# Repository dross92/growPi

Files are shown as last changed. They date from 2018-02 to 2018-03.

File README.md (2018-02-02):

# **growPi**

#### Envirologger / Fan Controller for Raspberry Pi ####
This is a 'HAT' for Raspberry Pi 3 B.  The objective of this circuit board is to control and optimize an environment for growing plants.  Integrated Fan controller regulates temperature.

### Connections ###
* Headers for up to five i2c connections (Vcc = 5V)
* Three 4-wire 12v PWM fans
* Three relays (Lights, Fan, Water Pump)
* 12v plug powers entire board & Pi
* Push Button for manual pump control

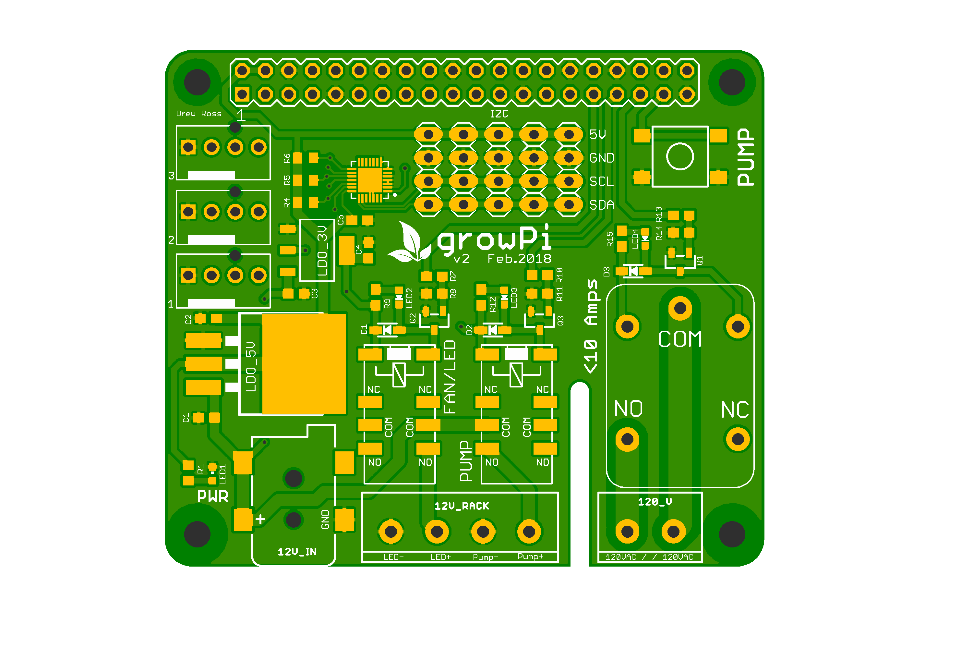
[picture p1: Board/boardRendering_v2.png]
Board


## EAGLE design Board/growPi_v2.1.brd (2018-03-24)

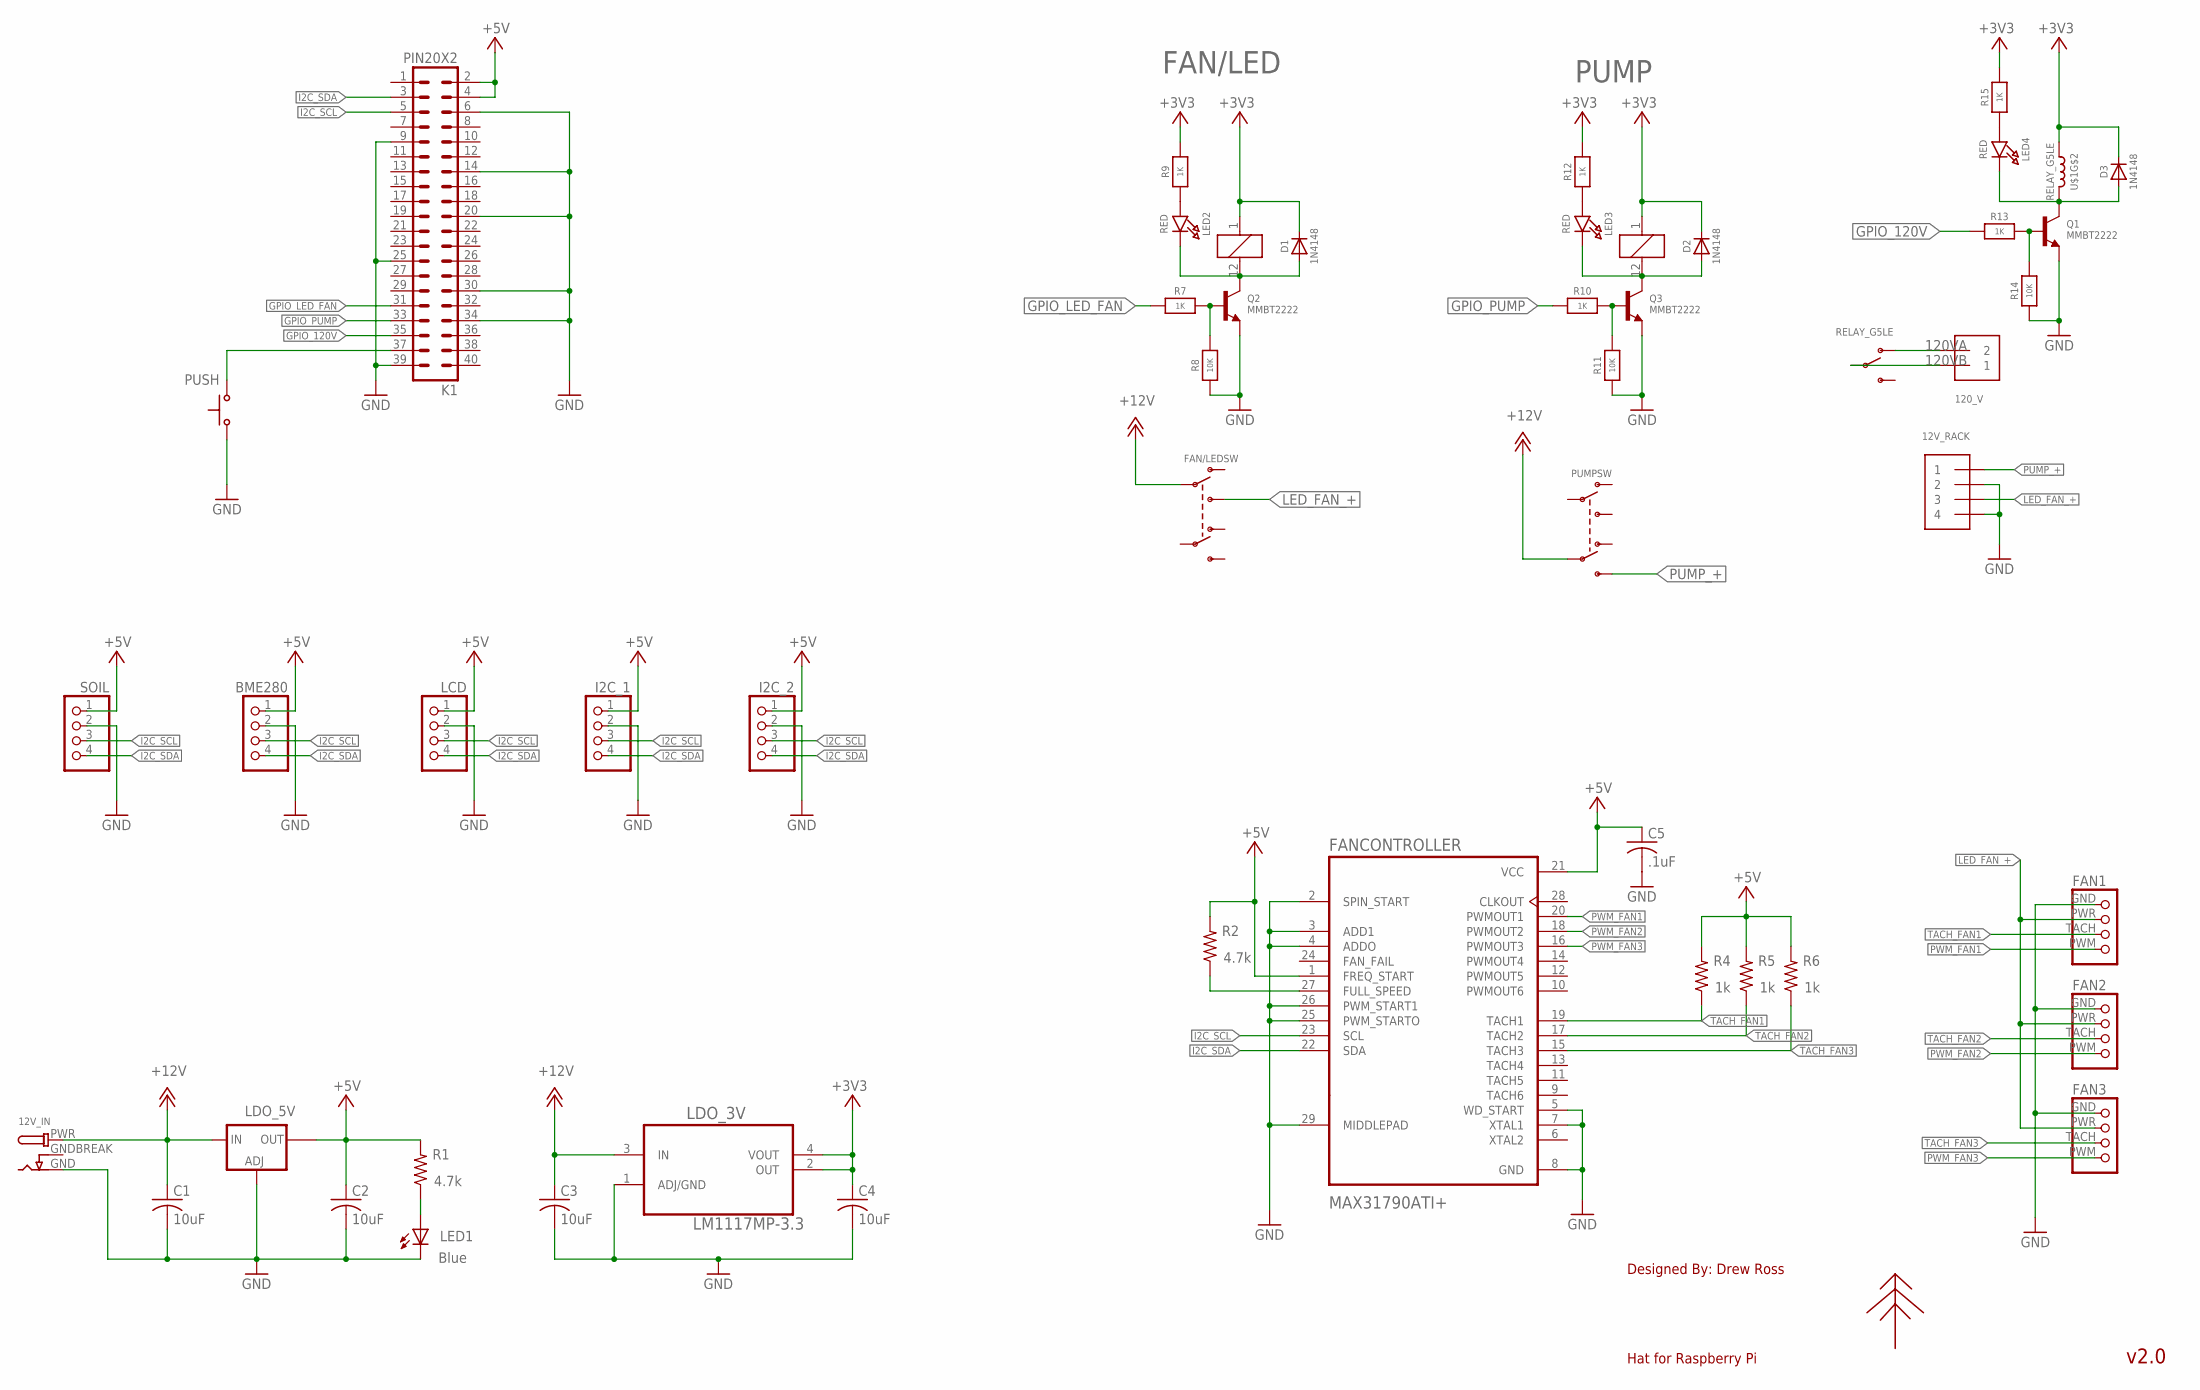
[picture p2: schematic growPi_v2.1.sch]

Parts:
12V_IN: DCBARRELSMT_CORRECT; DCJACK_2MM_SMT
12V_RACK: TERMBLOCK_1X4-5.0MM
120_V: TERMBLOCK_1X2-5.0MM
BME280: PINHD-1X4; 1X04
C1, C2, C3, C4: 10uF; C0603
C5: .1uF; C0603
D1, D2, D3: 1N4148; SOD-323
FAN1, FAN2, FAN3: 4PIN-MOLEX-FAN; 4PIN-FAN-HEADER
FAN/LED: RELAY_NONLATCHING-EE2NUH; RELAY_EE2_NOLATCH
FANCONTROLLER: MAX31790ATI+; QFN40P400X400X80-29N
I2C_1, I2C_2: PINHD-1X4; 1X04
K1: PIN20X2; PIN_20X2
LCD: PINHD-1X4; 1X04
LDO_3V: LM1117MP-3.3; SOT230P696X180-4N
LDO_5V: LM1084IS; TO263
LED1: Blue; CHIPLED_0603
LED2, LED3, LED4: RED; CHIPLED_0603_NOOUTLINE
PLANTLOGO: PLANTLOGO; PLANT
PUMP: RELAY_NONLATCHING-EE2NUH; RELAY_EE2_NOLATCH
PUSH: PTS645SSMTR; PTS645-SMD
Q1, Q2, Q3: MMBT2222; SOT23-R
R1, R2: 4.7k; R0603
R4, R5, R6: 1k; R0603
R7, R9, R10, R12, R13, R15: 1K; 0603-NO
R8, R11, R14: 10K; 0603-NO
SOIL: PINHD-1X4; 1X04
U$1: RELAY_G5LE; RELAY_G5LE-1

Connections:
120VA: 120_V.2, U$1.3 (O)
120VB: 120_V.1, U$1.1
+3V3: C4.1, D1.C, D2.C, D3.C, FAN/LED.1, LDO_3V.2 (OUT), LDO_3V.4 (VOUT), PUMP.1, R9.2, R12.2, R15.2, U$1.2 (1)
+5V: BME280.1, C2.1, C5.1, FANCONTROLLER.1 (FREQ_START), FANCONTROLLER.21 (VCC), I2C_1.1, I2C_2.1, K1.2, K1.4, LCD.1, LDO_5V.2 (OUT), R1.2, R2.2, R4.2, R5.2, R6.2, SOIL.1
+12V: 12V_IN.PWR, C1.1, C3.1, FAN/LED.9 (P1), LDO_3V.3 (IN), LDO_5V.3 (IN), PUMP.4 (P2)
GND: 12V_IN.GND, 12V_RACK.2, 12V_RACK.4, BME280.2, C1.2, C2.2, C3.2, C4.2, C5.2, FAN1.GND (1), FAN2.GND (1), FAN3.GND (1), FANCONTROLLER.2 (SPIN_START), FANCONTROLLER.3 (ADD1), FANCONTROLLER.4 (ADDO), FANCONTROLLER.5 (WD_START), FANCONTROLLER.7 (XTAL1), FANCONTROLLER.8 (GND), FANCONTROLLER.25 (PWM_STARTO), FANCONTROLLER.26 (PWM_START1), FANCONTROLLER.29 (MIDDLEPAD), I2C_1.2, I2C_2.2, K1.6, K1.9, K1.14, K1.20, K1.25, K1.30, K1.34, K1.39, LCD.2, LDO_3V.1 (ADJ/GND), LDO_5V.1 (ADJ), LED1.C, PUSH.1, PUSH.2, Q1.2 (E), Q2.2 (E), Q3.2 (E), R8.1, R11.1, R14.1, SOIL.2
GNDBREAK: 12V_IN.GNDBREAK
GPIO_120V: K1.35, R13.1
GPIO_LED_FAN: K1.31, R7.1
GPIO_PUMP: K1.33, R10.1
I2C_SCL: BME280.3, FANCONTROLLER.23 (SCL), I2C_1.3, I2C_2.3, K1.5, LCD.3, SOIL.3
I2C_SDA: BME280.4, FANCONTROLLER.22 (SDA), I2C_1.4, I2C_2.4, K1.3, LCD.4, SOIL.4
LED_FAN_+: 12V_RACK.3, FAN1.PWR (2), FAN2.PWR (2), FAN3.PWR (2), FAN/LED.8 (S1)
unnamed: FANCONTROLLER.27 (FULL_SPEED), R2.1
unnamed: D1.A, FAN/LED.12 (2), LED2.C, Q2.3 (C)
unnamed: Q2.1 (B), R7.2, R8.2
unnamed: LED2.A, R9.1
unnamed: D2.A, LED3.C, PUMP.12 (2), Q3.3 (C)
unnamed: Q3.1 (B), R10.2, R11.2
unnamed: D3.A, LED4.C, Q1.3 (C), U$1.5 (2)
unnamed: LED3.A, R12.1
unnamed: LED1.A, R1.1
unnamed: K1.37, PUSH.3 (S), PUSH.4 (S)
unnamed: Q1.1 (B), R13.2, R14.2
unnamed: LED4.A, R15.1
PUMP_+: 12V_RACK.1, PUMP.5 (S2)
PWM_FAN1: FAN1.PWM (4), FANCONTROLLER.20 (PWMOUT1)
PWM_FAN2: FAN2.PWM (4), FANCONTROLLER.18 (PWMOUT2)
PWM_FAN3: FAN3.PWM (4), FANCONTROLLER.16 (PWMOUT3)
TACH_FAN1: FAN1.TACH (3), FANCONTROLLER.19 (TACH1), R4.1
TACH_FAN2: FAN2.TACH (3), FANCONTROLLER.17 (TACH2), R5.1
TACH_FAN3: FAN3.TACH (3), FANCONTROLLER.15 (TACH3), R6.1

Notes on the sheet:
Designed By:
Hat for Raspberry Pi
Drew Ross
v2.0

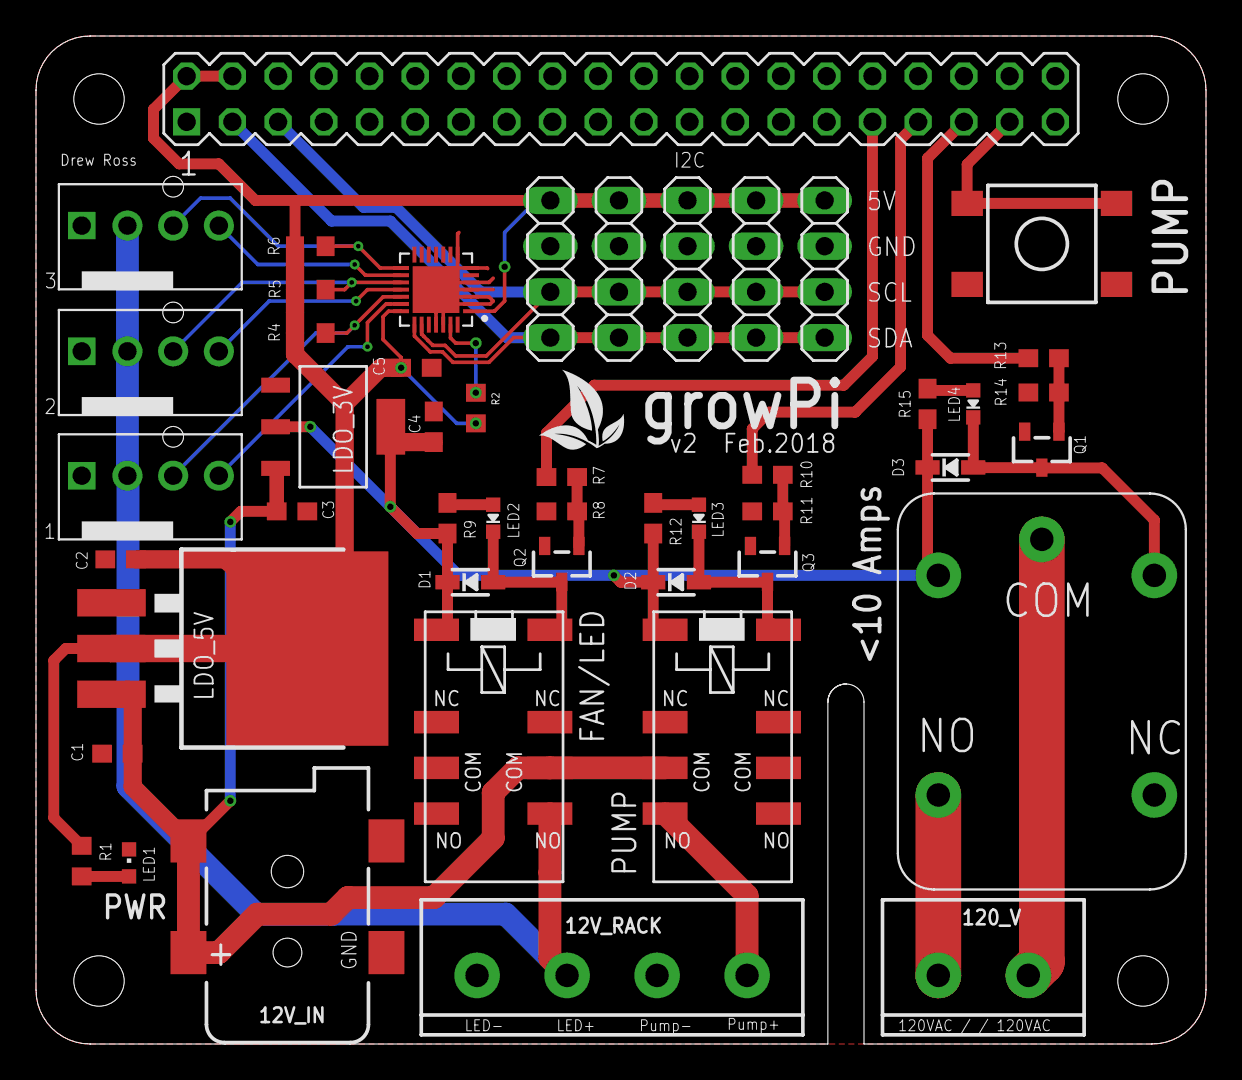
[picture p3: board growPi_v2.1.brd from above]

Board: 2 copper layers, 65.0 x 56.0 mm, 49 parts (0 on the bottom side), 31 nets.

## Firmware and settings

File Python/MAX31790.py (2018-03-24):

#!/usr/bin/python
"""
* MAX31790 6-Channel PWM-Output Fan RPM Controller Library
* 
* Author : Drew Ross
* 
* Notes:
* _ Use specifc POR settings from hardware
* - If less than 6 fans, use consecutive channels starting at 1
* - 
* - 
* - 
* 
"""

import smbus
import time

bus = smbus.SMBus(1)

#Characteristics
maxAddr = 0x20   # I2C Address (ADD0 & ADD1 = GND)
#maxAddr = 0x40 >> 1   #Datasheet defined 7bit address shifted = 0x20
pulsePerRev = 2  # Number of fan tach pulses  per fan revolution (NP)
tachPeriods = 4  # Chip Default - number of 8192Hz cycles per motor something (SR)


#------------------------Definitions----------------
#FREQS
PWMFREQ_25Hz  = 0b0000
PWMFREQ_30Hz  = 0b0001
PWMFREQ_35Hz  = 0b0010
PWMFREQ_100Hz = 0b0011
PWMFREQ_125Hz = 0b0100
PWMFREQ_5kHz  = 0b1001
PWMFREQ_25kHz = 0b1011

#Spin Up Behavior (2 tach pulses or Max time)
spin_0     = 0b00
spin_500ms = 0b01
spin_1s    = 0b10
spin_2s    = 0b11

#Number of Tach Periods Counted
tachPer_1  = 0b000
tachPer_2  = 0b001
tachPer_4  = 0b010
tachPer_8  = 0b011
tachPer_16 = 0b100
tachPer_32 = 0b101 # or 0b110 or 0b111 will work

#Time between Duty Cycle Increments (ms)
incr_1 = 0b000 # 0
incr_2 = 0b001 # 1.953125
incr_3 = 0b010 # 3.90625
incr_4 = 0b011 # 7.8125 - Default
incr_5 = 0b100 # 15.625
incr_6 = 0b101 # 31.25
incr_7 = 0b110 # 62.5
incr_8 = 0b111 # 125

# Sequential Fan Start Delay
t_0     = 0b000
t_250ms = 0b001
t_500ms = 0b010
t_1s    = 0b011
t_2s    = 0b100
t_4s    = 0b101 # or 0b110 or 0b111 wil work

# Duty Cycle on Failure
duty_0      = 0b00
duty_same   = 0b01
duty_100    = 0b10
duty_ALL100 = 0b11



#--------------------------------------------------------

#---------------------- Register MAP --------------------
#Single Registers
GLOBALCONFIG = 0x00
PWMFREQ = 0x01
SEQ_START = 0x14  #Also Fan Fail Settings

# Fan Config Reg 							02h - 07h
def FAN_CONFIG(channel):
	return 0x02 + (channel - 1)

# Fan Dynamics Reg 							08h - 0Dh
def FAN_DYNAMICS(channel):
	return 0x08 + (channel - 1)

# Read Tach Counter							18h - 23h  - For Fans 1-6
def TACH_COUNT_MSB(channel):
	return 0x18 + ((channel - 1) * 2)
def TACH_COUNT_LSB(channel):
	return 0x19 + ((channel - 1) * 2)

# Read Current PWM Duty Cycle 				30h - 3Bh
def PWM_OUT_DUTYCYCLE_MSB(channel):
	return 0x30 + ((channel - 1) * 2)
def PWM_OUT_DUTYCYCLE_LSB(channel):
	return 0x31 + ((channel - 1) * 2)

# Set Target PWM Duty Cycle 				40h - 4Bh
def PWMOUT_TARGET_MSB(channel):
	return 0x40 + ((channel - 1) * 2)
def PWMOUT_TARGET_LSB(channel):
	return 0x41 + ((channel - 1) * 2)

# Set Target Tach Counter					50h - 5Bh
def TACH_TARGET_COUNT_MSB(channel):
	return 0x50 + ((channel - 1) * 2)
def TACH_TARGET_COUNT_LSB(channel):
	return 0x51 + ((channel - 1) * 2)
#------------------------------------------------------


def writeBit(regAddr, bitNum, data):
	#Write single bit to 8-bit register
	regData = bus.read_byte_data(maxAddr,regAddr)
	writeData = (regData | (1 << bitNum)) if data == 1 else (regData & ~(1 << bitNum))
	bus.write_byte_data(maxAddr, regAddr, writeData)

def writeBits(regAddr, bitStart, length, data):
	#Write multiple bits to 8-bit register
	regData = bus.read_byte_data(maxAddr,regAddr)
	mask = ((1 << length) - 1) << (bitStart - length + 1)
	data = data << (bitStart - length + 1)
	data = data & mask
	writeData = (regData & ~(mask)) | data;
	bus.write_byte_data(maxAddr, regAddr, writeData)


def readReg(regNum):
	#Easier to type in python shell
	return bus.read_byte_data(maxAddr, regNum)

#Settings 
def reset():
	writeBit(GLOBALCONFIG, 6, 1)

def standbyMode():
	writeBit(GLOBALCONFIG, 7, 0)

def runMode():
	writeBit(GLOBALCONFIG, 7, 1)

def spinUp(channel, time):
	writeBits(FAN_CONFIG(channel), 6, 2, time)

def tachEnable(channel, bit):
	writeBit(FAN_CONFIG(channel), 3, bit)
	# 0 = Disable
	# 1 = Enable

def numTachPerCnt(channel, tachPer):
	writeBits(FAN_DYNAMICS(channel), 7, 3, tachPer)

def timeBtwDutyCycleIncr(channel, time):
	writeBits(FAN_DYNAMICS(channel), 4, 3, time)

def rateofChangeSymmetry(channel, bit):
	writeBit(FAN_DYNAMICS(channel), 1, bit)
	# 0 = Same RoC increasing/decreasing
	# 1 = RoC is half when drecreasing

def setSeqStartDelay(time):
	writeBits(SEQSTART, 7, 3, time)

def dutyCycleOnFail(duty):
	writeBits(SEQSTART, 3, 2, duty)

def faultQueue(numFaults):
	writeBits(SEQSTART, 1, 2, numFaults)

def initializeMAX(numberOfFans):
	reset()
	time.sleep(.1)
	for i in range(1,numberOfFans+1):
		#setRPM(i, MaxRPM)   		# Set MAX RPM for faults
		#setPWMTarget(i, 0)	 		# set intial PWM
		tachEnable(i, 1)	 		# Enable Tach input
		rateofChangeSymmetry(i, 1)	#Rate of Change slower when decreaseing
		print "Fan {:d} initialized".format(i)
	#print "MAX31790 Setup Complete"


#--------------------------------------------------

#PWM Functions
def PWMMode(channel):
	#Enable PWM Control Mode
	writeBit(FAN_CONFIG(channel), 7, 1)

def setPWMFreq( freq4_6 , freq1_3):
	#Set the PWM Frequency
	writeData = freq4_6 << 4 | freq1_3
	bus.write_byte_data(maxAddr, PWMFREQ, writeData)

def setPWMTarget(channel, ratePWM):  
	#set target PWM duty cycle in range (0,511)
	MSB = ratePWM >> 1
	LSB = (ratePWM & 0b1) << 7
	bus.write_byte_data(maxAddr, PWMOUT_TARGET_MSB(channel), MSB)
	bus.write_byte_data(maxAddr, PWMOUT_TARGET_LSB(channel), LSB) 

def setPWMTargetDuty(channel, percent):
	#set target PWM duty cycle in range (0,100)
	dutyCycle = (percent * 511) / 100
	MSB = dutyCycle >> 1
	LSB = (dutyCycle & 0b1) << 7
	bus.write_byte_data(maxAddr, PWMOUT_TARGET_MSB(channel), MSB)
	bus.write_byte_data(maxAddr, PWMOUT_TARGET_LSB(channel), LSB) 

def readPWM(channel):
	#read current PWM duty cycle in range (0,500)
	MSB = bus.read_byte_data(maxAddr,PWM_OUT_DUTYCYCLE_MSB(channel))
	LSB = bus.read_byte_data(maxAddr,PWM_OUT_DUTYCYCLE_LSB(channel)) 
	pwmNum = (MSB << 1) | (LSB >> 7)
	return pwmNum

def readPWMDuty(channel):
	#read current PWM duty cycle in range (0,100)
	MSB = bus.read_byte_data(maxAddr,PWM_OUT_DUTYCYCLE_MSB(channel))
	LSB = bus.read_byte_data(maxAddr,PWM_OUT_DUTYCYCLE_LSB(channel)) 
	pwmNum = (MSB << 1) | (LSB >> 7)
	return (pwmNum * 100) / 511	

def	readPWMTarget(channel):
	#Read current PWM target in range (0,511)
	MSB = bus.read_byte_data(maxAddr,PWMOUT_TARGET_MSB(channel))
	LSB = bus.read_byte_data(maxAddr,PWMOUT_TARGET_LSB(channel)) 
	pwmNum = (MSB << 1) | (LSB >> 7)
	return pwmNum	

#RPM Functions
def RPMMode(channel):
	#Enable RPM Control Mode
	writeBit(FAN_CONFIG(channel), 7, 0)

def setRPMTarget(channel, rateRPM):
	#Set the tach target in RPM
	tCount = (60 * (tachPeriods) * (8192)) / (pulsePerRev * rateRPM)
	MSB = (tCount >> 3)
	LSB = (tCount & 0b111) << 5
	bus.write_byte_data(maxAddr, TACH_TARGET_COUNT_MSB(channel), MSB)
	bus.write_byte_data(maxAddr, TACH_TARGET_COUNT_LSB(channel), LSB) 

def readRPM(channel):
	#Read the current tach count in RPM
	MSB = bus.read_byte_data(maxAddr, TACH_COUNT_MSB(channel))
	LSB = bus.read_byte_data(maxAddr, TACH_COUNT_LSB(channel))
	tCount = (MSB << 3) | (LSB >> 5)
	rpm = (60 * (tachPeriods) * (8192)) / (pulsePerRev * tCount)
	# My tach reads 480 when stopped
	if rpm == 480:
		rpm = 0 
	return rpm

def readRPMTarget(channel):
	#Read the current tach target in RPM
	MSB = bus.read_byte_data(maxAddr, TACH_TARGET_COUNT_MSB(channel))
	LSB = bus.read_byte_data(maxAddr, TACH_TARGET_COUNT_MSB(channel))
	tCount = (MSB << 3) | (LSB >> 5)
	return (60 * (tachPeriods) * (8192)) / (pulsePerRev * tCount)


#Usage Functions
def checkFaults():
	#Returns 0 if no faults
	return readReg(0x11) 

def StopAllFans(numberOfFans):
	for i in range (1,numberOfFans):
		setPWMMode(i)
		setPWMTarget(i,0)

def slowStopAllFans(numberOfFans):
	#NOT FUNCTIONAL
	for i in range (1,numberOfFans):
		setPWMTarget(i,20)
	while(readPwm(1) >20):
		pass
	for i in range (1,numberOfFans):
		setPWMTarget(i,0)

def fanTest():
	#Used to Map expected tach values for each duty cycle
	for i in range (0,512):
		setPWMTarget(1, i)
		time.sleep(.5)
		tachCt = readRPM(1)
		print "{:d}".format(i) + " | " + "{:d}".format(tachCt)



'''
def main():
	initialize(1)



if __name__=="__main__":
   main()
'''

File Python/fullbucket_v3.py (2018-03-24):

#!/usr/bin/python
#--------------------------------------
#    ___  ___  _  
#   / _ \/ _ \(_)_____ __ __ __ __     
#  / , _/ ___/ // _  // // // // /     
# /_/|_/_/  /_/ \_, / \___/ \_, /
#              /___/       /___/
#   
#           Envirologger / Fan Controller
#  Read data from a BME280  & Soil Moisture sensor
#  then sends the data to Thingspeak.com account.
#  Also controls fan speed with PWM based on temp data.
#
# Author : Drew Ross
# Updates   
#   02/20/2018 : fullbucket_v3 now using MAX31790 Fan controller with support for up to 6 fans
#   11/10/2017 : fullbucket v2 added soil data to thingspeak api & adds all data to LCD print
#   11/10/2017 : fullbucket_v1 integrated soil moisture into LCD printout
#   11/07/2017 : fullbucket_v0 initiated to consolidate into one script 
#   10/23/2017 : thingspeak data and fan control were seperate scripts to start 
#   10/12/2017 : fixed script crashing from URL post error by implementing try/except error handling  

#
#
#------------------------- References -------------------------------
# *Thingspeak*
#   https://www.raspberrypi-spy.co.uk/2015/06/basic-temperature-logging-to-the-internet-with-raspberry-pi/
#
# *BME280*
#   https://www.raspberrypi-spy.co.uk/2016/07/using-bme280-i2c-temperature-pressure-sensor-in-python/
#
# *Soil Moisture Sensor
#   https://github.com/Miceuz/i2c-moisture-sensor   ->Original
#   https://github.com/Apollon77/I2CSoilMoistureSensor    ->Arduino
#   https://github.com/ageir/chirp-rpi    ->rPi
#
# *PWM*
#   https://sourceforge.net/p/raspberry-gpio-python/wiki/PWM/
#   https://learn.sparkfun.com/tutorials/raspberry-gpio/python-rpigpio-api
#
# *LCD*
#   https://www.raspberrypi-spy.co.uk/2015/05/using-an-i2c-enabled-lcd-screen-with-the-raspberry-pi/
#
# *Interrupts*
#   http://raspi.tv/2013/how-to-use-interrupts-with-python-on-the-raspberry-pi-and-rpi-gpio
#
###############################################
#----------------Libraries---------------------
import smbus
import time
import os
import sys
import urllib            # URL functions
import urllib2           # URL functions
import RPi.GPIO as GPIO  # Raspberry Pi GPIO library
import bme280            # Temp / Humis Sensor library
import lcd_i2c           # i2C LCD library
import MAX31790          # MAX31790
import bmp280
#----------------------------------------------
###############i2c params######################
I2C_ADDR  = 0x27 # LCD I2C device address
BME_ADDR  = 0x76 #BME280  I2C address
BMP_ADDR  = 0x68 #BMP280 I2C Adress

SMBUSID   = 1    # 1: Pi 3 B SMBUS
###############################################
#----------------------------------------------
pushButton = 26   # Button BCM  
PUMP       = 13   # Pump BCM
counter    = 0    # For button press
#----------------------------------------------
###############Thingspeak info#################
INTERVAL      = 1                                     # Delay between each reading (mins)
THINGSPEAKKEY = 'ZEX2JMIAZHUXTG58'                    # API Write Key
THINGSPEAKURL = 'https://api.thingspeak.com/update'   # API URL
tz_local      = 'America/Chicago'                     # Local Timezone
###############################################
#----------------------------------------------
################LCD stuff######################
LCD_WIDTH  = 20     # Maximum characters per line
LCD_LINE_1 = 0x80   # LCD RAM address for the 1st line
LCD_LINE_2 = 0xC0   # LCD RAM address for the 2nd line
LCD_LINE_3 = 0x94   # LCD RAM address for the 3rd line
LCD_LINE_4 = 0xD4   # LCD RAM address for the 4th line
###############################################

def sendData(url,key,field1,field2,field3,field4,temp,pres,humid,tempf):
    """
    Send event to Thingspeak internet site
    """
    values = {'api_key' : key,'field1' : temp,'field2' : pres,'field3' : humid,'field4' : tempf,'timezone' : tz_local}

    postdata = urllib.urlencode(values)     #encode values in url format  ------> (postdata) = api_key=key&field1=temp&field2=pres ....
    req = urllib2.Request(url, postdata)    #attach to URL request  ------> (req) = http://www.thingspeak.com/update?(postdata)

    log = time.strftime("%Y-%m-%d %H:%M:%S") + " | " 
    log = log + "{:.2f} C".format(temp) + " | "
    log = log + "{:.2f} F".format(tempf) + " | "
    log = log + "{:.2f} mBar".format(pres) + " | "
    log = log + "{:.2f} %".format(humid) + " | "
    
    try:
        # Send data to Thingspeak
        response = urllib2.urlopen(req, None, 5)  #open URL (req) to post data to server
        html_string = response.read()             # server returns update number
        response.close()
        log = log + 'Update ' + html_string
    # Error handling so script doesnt break
    except urllib2.HTTPError, e:
        log = log + 'Server could not fulfill the request. Error code: ' + e.code
    except urllib2.URLError, e:
        log = log + 'Failed to reach server. Reason: ' + e.reason
    except:
        log = log + 'Unknown error'

    print log

def BUTTON(channel):
    global counter
    if GPIO.input(26) == 1:
        if counter % 2 == 0:        #check if even
            GPIO.output(PUMP,1)
        else:
            GPIO.output(PUMP,0)
        counter += 1
        if counter == 100:           #keep counter low
            counter =0
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

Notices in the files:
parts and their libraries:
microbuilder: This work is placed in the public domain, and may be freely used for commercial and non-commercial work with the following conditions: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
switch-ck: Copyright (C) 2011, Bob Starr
